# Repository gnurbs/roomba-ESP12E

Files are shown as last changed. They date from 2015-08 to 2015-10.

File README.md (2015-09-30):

# ESP12E WiFi microcontroller for Roombas

track and (remote-) control Roombas

## Hardware
current focus - see [hardware branch](https://github.com/gnurbs/roomba-ESP12E/tree/hardware)
- connects to Roomba's serial Port
- ESP12E module
- buck power converter
- serial header for programming / observing Roomba / ESP12E communication for debugging
- expansion header with unused ESP12E pins 

## ESP12E Software
we're using the [nodemcu Firmware](https://github.com/nodemcu/nodemcu-firmware)
- udp2uart: udp <-> uart proxy. Broken as we need hardware to continue
- server.lua: very limited Rooomba controlling HTTP server that can trigger wakeup, short straight drive and clean
- lib.lua: helper functions one would expect in the std library, added and with functionality as needed

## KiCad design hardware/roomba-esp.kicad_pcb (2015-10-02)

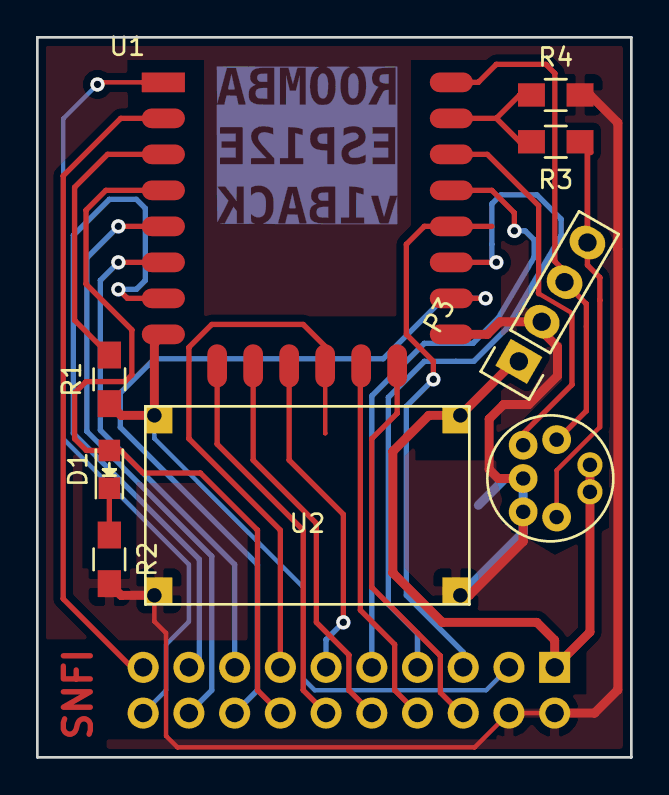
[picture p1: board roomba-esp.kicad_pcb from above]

Board: 2 copper layers, 33.0 x 40.0 mm, 10 parts (1 on the bottom side), 25 nets.

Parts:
D1: LED; LED-0805
P1: CONN_01X07; mini_DIN_7
P2: CONN_02X10; Socket_Strip_Angled_2x10
P3: CONN_01X04; Socket_Strip_Straight_1x04
R1, R4: 10K; R_0805_HandSoldering
R2: 1K; R_0805_HandSoldering
R3: 5K; R_0805_HandSoldering
U1: ESP-12E
U2: LM2596_module

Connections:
/ADC: P2.19, U1.2
/CS0: P2.12, U1.9
/DD: P1.5, U1.20
/GPIO0: P2.5, U1.18
/GPIO2: P2.7, U1.17
/GPIO5: P2.9, U1.19
/GPIO9: P2.11, U1.11
/GPIO10: P2.13, U1.12
/GPIO12: P2.15, U1.6
/GPIO13: P2.17, U1.7
/GPIO14: P2.18, U1.5
/GPIO15: P2.16, U1.16
/GPIO16: D1.2, P2.14, U1.4
/MISO: P2.10, U1.10
/MOSI: P2.8, U1.13
/RESET: P2.20, U1.1
/RX: R3.2, R4.1, U1.21
/RX_R: P1.3, P3.3, U1.22
/SCK: P2.6, U1.14
/TX_R: P1.4, P3.4, R3.1
/VBat: P1.1, P1.2, P2.1, P3.1, U2.4
GND: P1.6, P1.7, P2.2, P2.4, P3.2, R2.2, R4.2, U1.15, U2.2, U2.3
unnamed: D1.1, R2.1
unnamed: R1.2, U1.3
VCC: P2.3, R1.1, U1.8, U2.1

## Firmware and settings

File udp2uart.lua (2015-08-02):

ESSID = 'APF_swooooosh'

wifi.setmode(wifi.STATION)
wifi.sta.config(ESSID,PSK)
srv = net.createServer(net.UDP)
reqAnsLen = { 26,10,6,10 }

-- setup UART to 115200 8N1
uart.setup(0,115200,8,0,1,0)

-- poke roomba awake
gpio.mode(8,gpio.OUTPUT)
gpio.write(8,1)
tmr.delay(50000)
gpio.write(8,0)
gpio.mode(8,gpio.INPUT)

-- light up user LED
gpio.mode(0,gpio.OUTPUT)
gpio.write(0,0) -- low is the new high, i.e. LED is connected to vcc

function uart_rx_cb(c)
    -- writes from uart to data
    -- the uart rx callback is extremely strange:
    -- it goes into a loop if it does not deregister itself. SWTF.
    -- maybe it does not go into loop, but rather while rx cb registered no chars
    -- go to lua shell, so it is effectively disconnected

    srv:send(c)
    uart.on('data')
end

function rx2uart(sock,cmd)
    if cmd:byte(1) == 142 then
        local len = reqAnsLen[cmd:byte(2)]
        -- deregister callback if no data received
        tmr.alarm(0,30,0,function() uart.on('data') end)
        uart.on('data',len,uart_rx_cb,0)
    end
    uart.write(0,cmd)
 end

srv:listen(33)
srv:on('receive',rx2uart)

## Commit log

2015-08-02 made led working
2015-08-03 added kicad-ESP8266 submodule
2015-08-20 initial schematics
    [roomba-esp.kicad_pcb, roomba-esp.sch]
2015-09-22 LM2596 buck module
2015-09-22 mini DIN 7 straight connector module
2015-09-22 initial version with unfinished pcb
    [roomba-esp.dsn, roomba-esp.sch]
2015-09-22 kicad gitignore: cache+bak
2015-09-22 removed kicad cruft from git
2015-09-22 finalised rev0 pcb
    [roomba-esp.kicad_pcb, roomba-esp.sch]
2015-09-22 fixed some kicad-level path/library setings
    [roomba-esp.kicad_pcb]
2015-09-27 added voltage divider on ESP RX to accomodate for 5V level on 3.3V pin
    [roomba-esp.kicad_pcb, roomba-esp.sch]
2015-09-27 gitignored kicad_pcb-bak
2015-09-27 rearrenged roomba connector and voltage divider
    [roomba-esp.kicad_pcb]
2015-09-27 added additional connector to serial in schematic
    [roomba-esp.sch]
2015-09-27 added serial header to pcb
    [roomba-esp.kicad_pcb]
2015-10-02 added some keepout areas to increases manufacture reliability
    [roomba-esp.kicad_pcb]
2015-10-02 create artwork on pcb
    [roomba-esp.kicad_pcb]
2015-10-02 gerber files for bastli
    [roomba-esp-B_Cu.gbr, roomba-esp-Edge_Cuts.gbr, roomba-esp-F_Cu.gbr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]
